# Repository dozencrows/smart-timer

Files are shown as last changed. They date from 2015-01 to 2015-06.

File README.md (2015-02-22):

smart-timer
===========
This is a test project for exploration of the NXP LPC810 ARM microcontroller.

It implements a dual countdown timer, capable of up to ten hour countdowns on each timer independently.

There is accompanying hardware that the code requires:
* MCP23008 I2C GPIO expander to interface 8 momentary switches to act as input
* 2N2222 transistor switching a piezo self-oscillating sounder
* MIC2545A smart switch controlling LCD power
* 16 x 2 character LCD display (hd44780 compatible)
* PCF8574 I2C GPIO expander to interface LCD display
* 3.3V power supply

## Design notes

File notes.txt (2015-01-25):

Smart Kitchen Timer - Design & Development Notes
================================================

Timer appearance: H:MM:SS

Two timer displays.

Buttons per timer:
    H:      +1 hour, stops timer
    M:      +1 minute, stops timer
    S:      +1 second, stops timer
    start:  toggle timer start/stop

Combined button actions:
    start and any of H, M, S buttons: stops & resets timer to 0:00:00.
    start1 + start2: toggle timer mode

Timer modes:
    Independent: each timer can be started & stopped independently.
    Chained: timer 1 runs first; on completion, triggers timer 2.
        Resetting either timer resets both.
        Actions that stop a timer stop both if running.
    
Alarm state:
    On reaching 0:00:00, a timer stops, emits an audible alarm and its display flashes.
    Pressing any button for that timer cancels the alarm, sets the timer back to starting value.

Structure:
    2 x timers
    1 x timer controller
    1 x alarm
    1 x input manager
    
Timer:
    States:
        STOPPED
        RUNNING
        PAUSED
        ALARM
    Events:
        Button events:
            H_b
            M_b
            S_b
            start_b
            start_b + H_b/M_b/S_b
        Control events:
            start
            stop
            update
            reset
            alarm
    Data:
        Current state
        Current H, M, S
        Starting H, M, S
    Behaviour:
        Global:
            reset:                  set H, M and S to zero, change to STOPPED state
            start_b + H_b/M_b/S_b:  send timer X reset event to controller
        
        STOPPED:
            H_b, M_b, S_b:          increment corresponding data and refresh display
            start_b:                send timer X start event to controller
            start:                  go to RUNNING state
            update:                 refresh display
            
        RUNNING:
            start_b, H_b, M_b, S_b: send timer X stop event to controller
            update:                 count down timer, refresh display - if zero, send timer X done to controller
            stop:                   go to PAUSED state
            alarm:                  go to ALARM state
            
        PAUSED:
            start_b, H_b, M_b, S_b: send timer X start event to controller
            update:                 refresh display
            start:                  go to RUNNING state
            
        ALARM:
            update:                 flash and refresh display
            start_b, H_b, M_b, S_b: set H, M, S to starting values, go to STOPPED state
        
Timer Controller:
    States:
        INDEPENDENT
        CHAINED
    Events:
        Button events:
            start_b1+start_b2
        Timer events:
            timer 1 start
            timer 2 start
            timer 1 stop
            timer 2 stop
            timer 1 reset
            timer 2 reset
            timer 1 done
            timer 2 done
    Data:
        current state
    Behaviour:
        Global:
            any:                    send clear to Alarm
        
        INDEPENDENT:
            timer X start:          send start to timer X
            timer X stop:           send stop to timer X
            timer X reset:          send reset to timer X
            timer X done:           send trigger to Alarm, send alarm to timer X
            
        CHAINED:
            timer X start:          if timer 1 running, send start to timer 1
                                    if timer 2 running, send start to timer 2
            timer X stop:           if timer 1 running, send stop to timer 1
                                    if timer 2 running, send stop to timer 2
            timer X reset:          send reset to timer 1 and timer 2
            timer X done:           if X == 1:
                                        send trigger to Alarm, send alarm to timer 1, send start to timer 2
                                    if X == 2:
                                        send trigger to Alarm, send alarm to timer 2        

Alarm:
    States:
        SILENT
        AUDIBLE
    Events:
        trigger
        clear
    Behaviour:
        Global:
        
        SILENT:
            trigger:    start audible alarm, go to AUDIBLE state
            
        AUDIBLE:
            clear:      stop audible alarm, go to SILENT state

Total events - 19:
    alarm trigger       Alarm control
    alarm clear
    timer 1 start       Timer controller notifications
    timer 2 start
    timer 1 stop
    timer 2 stop
    timer 1 reset
    timer 2 reset
    timer 1 done
    timer 2 done
    timer start         Timer behaviour control
    timer stop
    timer update        Model as update handler func
    timer reset
    timer alarm
    H_b                 Treat button combos as bitwise or of button events
    M_b
    S_b
    start_b
    
State Machine Design
    State:              
        enter func ptr
        event handler func ptr
        update handler func ptr
        exit func ptr
    States:
        array of structures
    Event handler:
        switch statement on event flag combos.
    Functions:
        get state
        set state

Input Manager
    Polls GPIO buttons/reads interrupt results
    Debounces and records combos
    Sends button events to appropriate timer
    
Count-down timers
    Use an MRT for each.
        Set value to full duration & start; read back value & convert to H:MM:SS for display, use callback to trigger done.
        Set a repeat MRT to expire after 1 second; use callback on that to update timer counts (simpler, less code?)

Available Piezo Sounders
========================
Bitsbox:
* ST013:    Murata PKM13EPYH40002 - 4kHz, external drive
* ST045:    Emech 2048kHz - electromagnetic! 'Ware polarity, may only be up to 3V. Wire diode in reverse in parallel instead of resistor.
* KPEG200A: Kingstate - continuous tone, just requires DC. 2600Hz - 3600Hz. 1.3mA draw.
* ST016:    ? - continuous tone, just requires DC. 2700Hz. 4.7mA draw.

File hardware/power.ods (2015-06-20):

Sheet: Sheet1
Battery capacity mAH | 1800 | Hours | Days
Idle draw mA | 0.319 | 5642.6332288401 | 235.1097178683
Input draw mA | 21 | 85.7142857143 | 3.5714285714
Timer draw mA | 5 | 360 | 15
Alarm draw mA | 9 | 200 | 8.3333333333

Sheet: Sheet2
Idle draw
3V3 side measured (mA) | 0.355
I2C level shift (mA) | 0.047
MCP23008 standby (mA) | 0
LPC810 deep sleep (mA) | 0.24 | R | 2.5 | V | 0.0006
3V3 from datasheet
LPC810 deep sleep (mA) | 0.3
MCP23008 standby (mA) | 0.001
MCP1700-3302 quiescent (mA) | 0.004
5V side measured (mA) | 0.458
I2C level shift (mA) | 0.448
LCD leakage (mA) | 0
MIC2454A (switch off) + LCD leakage (mA) | 0
5V from datasheet
MCP1700-5002 quiescent (mA) | 0.004
MIC2454A switch off (mA) | 0.005

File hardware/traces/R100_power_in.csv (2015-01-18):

trigger | stamp | channel | index | type | delay | factor | rate | count | data
20111 | 15:43:18 | 0 | 20110 | 0 | 5E-7 | 5 | 1.8E6 | 900 | 0.063375 | 0.056243 | 0.056604 | 0.052813 | 0.052813 | 0.052135 | 0.051052 | 0.050781 | 0.051142 | 0.050781 | 0.050014 | 0.050285 | 0.05024 | 0.050781 | 0.050781 | 0.050781 | 0.050781 | 0.050059 | 0.050375 | 0.050781 | 0.050601 | 0.05024 | 0.050962 | 0.050962 | 0.050781 | 0.051097 | 0.051549 | 0.051187 | 0.051594 | 0.049247 | 0.052135 | 0.051955 | 0.051278 | 0.051458 | 0.051368 | 0.051549 | 0.052 | 0.059312 | 0.065993 | 0.066083 | 0.063194 | 0.059132 | 0.055521 | 0.053174 | 0.05209 | 0.051187 | 0.051413 | 0.050059 | 0.05024 | 0.05033 | 0.05033
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

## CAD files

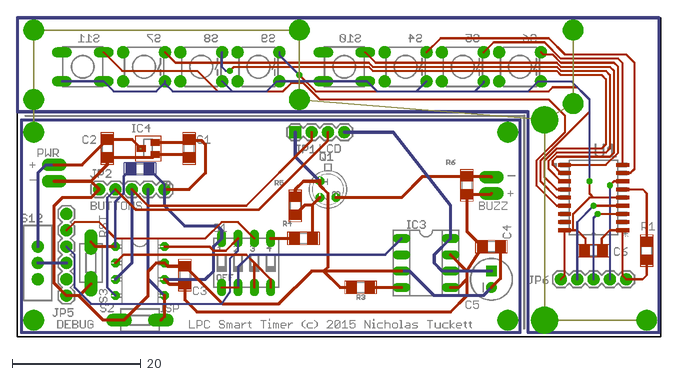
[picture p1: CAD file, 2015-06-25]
hardware/smart-timer-23009.dxf
100.2 x 49.7

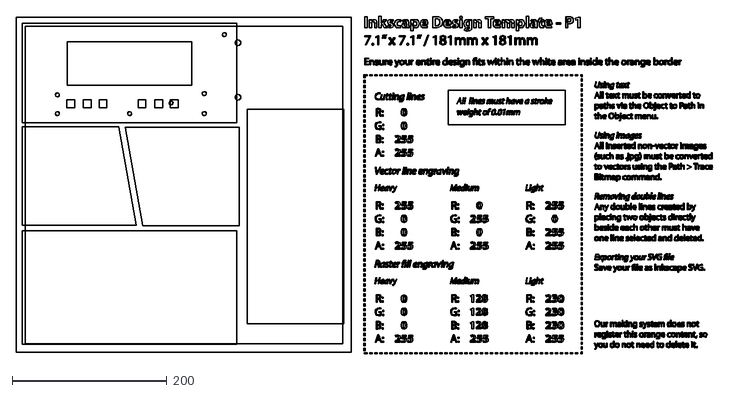
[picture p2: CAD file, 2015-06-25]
hardware/case.dxf
900.1 x 436.6

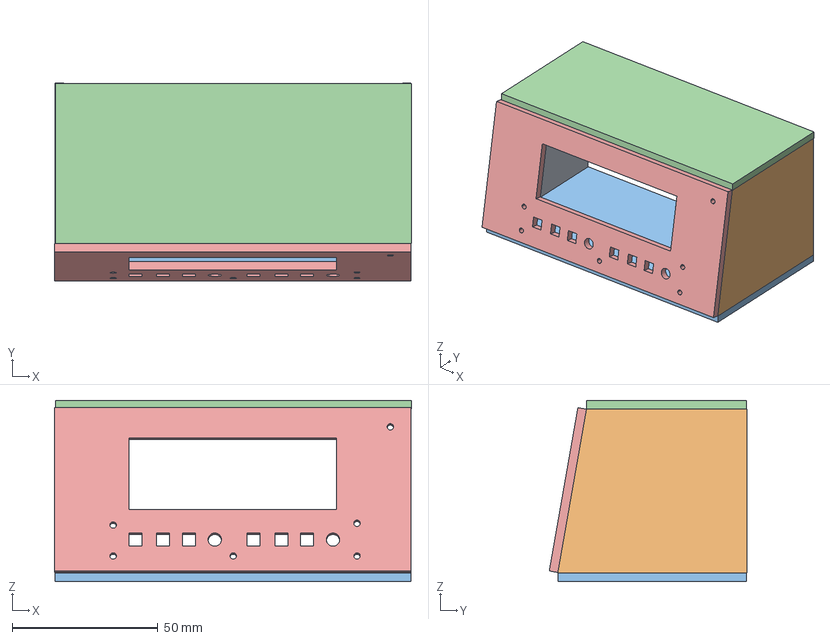
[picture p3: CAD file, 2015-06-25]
hardware/smart-timer-case.fcstd
122.6 x 67.8 x 62.2 mm
Cut014 (Solid)

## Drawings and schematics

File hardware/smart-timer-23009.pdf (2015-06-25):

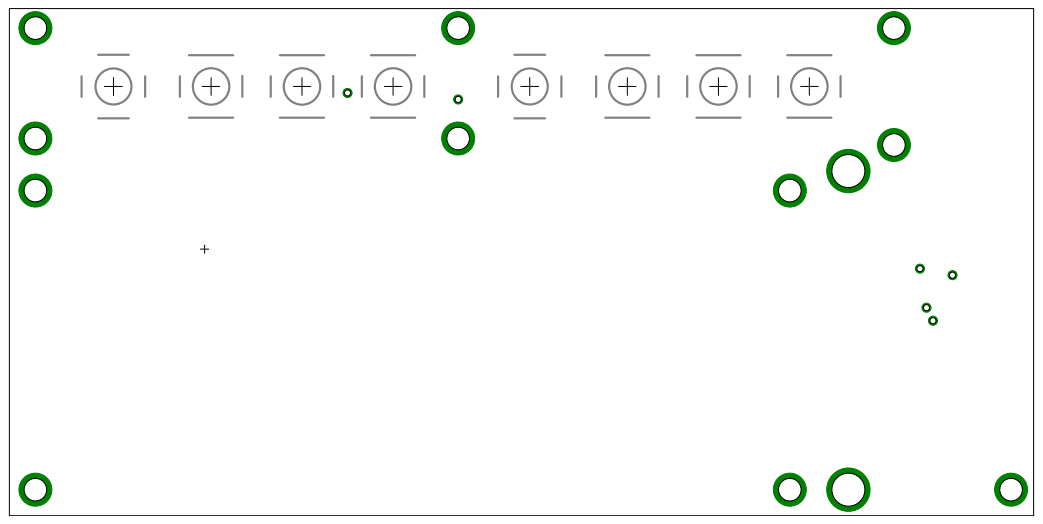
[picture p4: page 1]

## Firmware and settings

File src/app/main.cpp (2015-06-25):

//=======================================================================
// Copyright Nicholas Tuckett 2015.
// Distributed under the MIT License.
// (See accompanying file license.txt or copy at
//  http://opensource.org/licenses/MIT)
//=======================================================================

// Port & pin usage:
//	Pin	Port	Dir	    Usage			        Pull	Default
//	-----------------------------------------------------------------
//	1	PIO0_5	In	    Reset			        Up	    Reset (in)
//	2	PIO0_4	Out	    Buzzer on/off, UART TXD	Up	    PIO0_4 (in), UART TXD in ISP
//	3	SCL	    Out	    I2C			            Up	    SWDIO
//	4	SDA	    In/Out	I2C			            Up	    SWCLK
//	5	PIO0_1	In	    Button interrupt	    Up	    PIO0_1 (in), ISP if low on reset
//	6	VDD		        Power
//	7	VSS		        Ground
//	8	PIO0_0	Out	    LCD power		        Up	    PIO0_0 (in), UART RXD in ISP
//

// Programming mode means:
//  Switch LCD power connection to UART RXD (and force actual power switch to high)
//  Switch Buzzer connection to UART TXD

// Debugging mode means
//  Switch Buzzer connection to UART TXD

#include "string.h"
#include "serial.h"

#include "lpc_types.h"
#include "romapi_8xx.h"

#include "util/timers.h"
#include "util/lcd.h"
#include "util/mrt_interrupt.h"

#include "timer_controller.h"
#include "buzzer.h"
#include "backlight.h"
#include "button_input.h"


// Set this define to add debugging aids in code, and configure UART
// output to replace buzzer control
//#define DEBUG

#define LOOP_STEP_MS        64
#define BUZZER_GPIO         4
#define INPUT_I2C_ADDR      0x20

uint32_t SystemMainClock = FIXED_CLOCK_RATE_HZ;
uint32_t SystemCoreClock = FIXED_CLOCK_RATE_HZ;

const char hexdigit[] = "0123456789abcdef";

uint32_t i2cBuffer [24];
I2C_HANDLE_T* ih;

void error(const char* msg) {
    puts("\n**ERROR: ");
    puts(msg);
    putchar('\n');
}

void errorWithCode(const char* msg, int code) {
    puts("\n**ERROR: ");
    puts(msg);
    putchar(' ');
    
    for (int i = 24; i >= 0; i-=4) {
        putchar(hexdigit[(code >> i) & 0xf]);
    }
    putchar('\n');
}

static void i2cSetup () {
    LPC_SWM->PINENABLE0 |= 3<<2;            // disable SWCLK and SWDIO

    // Keep internal pull-ups on I2C pins, as this works and is less
    // power draining when LCD off and in low power state
    
    LPC_SWM->PINASSIGN7 = 0x02FFFFFF;       // SDA on P2, pin 4
    LPC_SWM->PINASSIGN8 = 0xFFFFFF03;       // SCL on P3, pin 3
    LPC_SYSCON->SYSAHBCLKCTRL |= (1<<5);    // enable I2C clock

    ih = LPC_I2CD_API->i2c_setup(LPC_I2C_BASE, i2cBuffer);
    if (ih == NULL)
        error("i2c_setup");
        
    if (LPC_I2CD_API->i2c_set_bitrate(ih, 12000000, 100000) != LPC_OK)
        error("i2c_set_bitrate");

    if (LPC_I2CD_API->i2c_set_timeout(ih, 100000) != LPC_OK)
        error("i2c_set_timeout");
}

static void configureLowPowerPins() {
    // Set PIO0_10 and 11 as low outputs, as they float.
    // This saves some power
    LPC_GPIO_PORT->DIR0 |= 3 << 10;
    LPC_GPIO_PORT->CLR0  = 3 << 10;
}

static void deepSleep() {
    LPC_SYSCON->STARTERP0   = 0x01; // pin interrupt 0 will wakeup 
    LPC_PMU->PCON           = 0x01; // select deep sleep
    SCB->SCR                = SCB_SCR_SLEEPDEEP_Msk;
    __WFI();
    LPC_PMU->PCON           = 0;
    SCB->SCR                = 0;
}

static void powerDown() {
    LPC_SYSCON->STARTERP0   = 0x01; // pin interrupt 0 will wakeup 
    LPC_PMU->PCON           = 0x02; // select power down
    SCB->SCR                = SCB_SCR_SLEEPDEEP_Msk;
    __WFI();
    LPC_PMU->PCON           = 0;
    SCB->SCR                = 0;
}

static void lcdPowerOn() {
    LPC_GPIO_PORT->B0[0] = 1;
}

static void lcdPowerOff() {
    LPC_GPIO_PORT->B0[0] = 0;
}

static void initLcdPowerSwitch() {
    LPC_SWM->PINASSIGN0 |= 0xff00;          // ensure pin 8 is not assigned to UART RXD  
    LPC_GPIO_PORT->DIR0 |= 1;               // set GPIO 0 output (to control LCD power)
    lcdPowerOn();
}

int main () {
#if defined(DEBUG)
    // Ensure UART TXD is on 
    LPC_SWM->PINASSIGN0 &= 0xffffff00;
    LPC_SWM->PINASSIGN0 |= 0x00000004;
#else
    LPC_SWM->PINASSIGN0 |= 0xff;
#endif

    configureLowPowerPins(); 
    timersInit();
    serial.init(LPC_USART0, FIXED_UART_BAUD_RATE);
    delayMs(100);
    puts("Smart Timer");
    i2cSetup();
    
    initLcdPowerSwitch();
        
    Buzzer::Initialise();
    Timer::Initialise();
    Backlight::Initialise();
    ButtonInput::Initialise();

    lcdInit();
    
    Backlight       backlight;
    Buzzer          buzzer(BUZZER_GPIO);
    TimerController timer_controller(buzzer, backlight);
    ButtonInput     button_input(INPUT_I2C_ADDR);
    
    mrt_interrupt_control(true);
    backlight.DelayedOff(BACKLIGHT_ON_TIME_MS);
    
    while (true) {
        while (button_input.HasButtonStateChanged()) {
            timer_controller.ProcessButtons(button_input.GetButtonStates());
        }

        timer_controller.Update();
        
        if (!button_input.HasButtonStateChanged()) {
            if (timer_controller.IsIdle() && !backlight.IsOn()) {
                lcdPowerOff();
                powerDown();

                lcdPowerOn();
                delayMs(10);
                
                backlight.On();
                buzzer.Beep();
                
                if (button_input.HasButtonStateChanged()) {
                    button_input.DiscardNextState();
                }
                
                lcdInit();
                timer_controller.ForceUpdate();
            }
            else {
                __WFI();
            }
        }
    }
}

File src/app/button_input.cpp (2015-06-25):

//=======================================================================
// Copyright Nicholas Tuckett 2015.
// Distributed under the MIT License.
// (See accompanying file license.txt or copy at
//  http://opensource.org/licenses/MIT)
//=======================================================================

/*
 * GPIO extender button input implementation
 *
 * Sets up MCP23008 expander for all pins to be inputs with pull-ups.
 * Assumes MCP23008 interrupt pin is connected to PIO0_1 (pin 5 on LPC810)
 * PIO0_1 is left in default post-reset state:
 *  - its PINENABLE0 bit is 1 so no special function is active - no change needed
 *  - GPIO means no movable function should be assigned to this pin - no change needed
 *  - Input GPIO means 0 in bit for direction register - no change needed
 */
 
#include "button_input.h"

#include "LPC8xx.h"
#include "util/mcp.h"
#include "util/timers.h"

#define POST_READ_DELAY_MS  8

static volatile int buttonIRQCount = 0;

extern "C" void PININT0_IRQHandler(void) {
    if (LPC_PIN_INT->FALL & 1) {
        LPC_PIN_INT->FALL = 1;
        buttonIRQCount++;
    }
}

void ButtonInput::Initialise() {
    // Configure pin interrupt for PIO0_1
    LPC_SYSCON->PINTSEL[0]      = 1;        // Pin interrupt 0 from PIO0_1
    LPC_PIN_INT->ISEL           = 0;        // Level sensitive (1 bit per pin interrupt)
    LPC_PIN_INT->IENF           = 1;        // Falling level   (1 bit per pin interrupt)
    LPC_SYSCON->SYSAHBCLKCTRL  |= 1<<6;     // Turn on clock to pin interrupts block (already 1 after reset)
    NVIC_EnableIRQ(PININT0_IRQn);           // Enable pin interrupt in NVIC (#24)
}

ButtonInput::ButtonInput(uint8_t i2c_addr) : i2c_addr_(i2c_addr), button_state_(0) {
    mcpWriteRegister(i2c_addr_, MCP23008_IODIR, 0xff);   // 0-7: input
    mcpWriteRegister(i2c_addr_, MCP23008_GPPU, 0xff);    // 0-7: pull-up
    mcpWriteRegister(i2c_addr_, MCP23008_IPOL, 0xff);    // 0-7: invert
    mcpWriteRegister(i2c_addr_, MCP23008_GPINTEN, 0xff); // 0-7: interrupt on change. Interrupt pin is active low
}

uint8_t ButtonInput::GetButtonStates() {
    if (buttonIRQCount > 0) {
        __disable_irq();
        buttonIRQCount--;
        __enable_irq();
        button_state_ = mcpReadRegister(i2c_addr_, MCP23008_GPIO);
    }
    
    return button_state_;
}

void ButtonInput::DiscardNextState()
{
    GetButtonStates();
}

bool ButtonInput::HasButtonStateChanged() {
    return buttonIRQCount > 0;
}

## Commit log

2015-01-04 Initial implementation and test of fundamental countdown timer
2015-01-04 Added flashing alarm state to timers
2015-01-04 Implemented timer controller for independent timers
2015-01-04 Refactored buzzer into its own controller class, and added beep capability
    [buzzer.cpp, main.cpp]
2015-01-18 Added hardware folder, with test oscilloscope trace
    [R100_power_in.csv]
2015-01-18 Switched to MCP23008 as GPIO extender
2015-01-18 Only read from MCP GPIO extender on its interrupt signal
2015-01-19 WIP on interrupt driven main loop
2015-01-20 Refine button IRQ handling to improve responsiveness
2015-01-20 Buzzer now only turns on SysTick interrupt when active
    [buzzer.cpp]
2015-01-24 Refactored button reading via GPIO into separate module; removed printf to save memory
2015-01-24 Finished refactoring button input handling
2015-01-25 Added continuous tone buzzer support; notes & plan update for piezo sounder tests
    [buzzer.cpp]
2015-01-28 Implemented deep-sleep mode for saving some power
2015-01-28 WIP: switching LCD power from GPIO
2015-01-31 WIP: turn off LCD as power save
2015-01-31 Move LCD GPIO power setup to earlier in startup
2015-02-06 Added power calculation sheet
    [power.ods]
2015-02-06 Updated sleep mode for active-high smart switch instead of MOSFET
2015-02-07 Experiment with I2C disabling to see if power saved - but doesn't
    [main.cpp]
2015-02-07 Removed i2c disable code. Fixed early return to sleep on short button press
    [main.cpp]
2015-02-15 Updated power calcs with switch to 3.3v LCD
    [power.ods]
2015-04-12 Switch to power down mode for greater power save
    [power.ods]
2015-05-13 Switched buzzer pin to allow RESET, added debug mode with UART switched in
    [main.cpp]
2015-05-14 Added note on I2C pull ups in low power state, and removed temps
2015-06-20 Revised button mapping to match PCB
    [power.ods]
2015-06-25 Added case design files
    [case.dxf, smart-timer-23009.dxf, smart-timer-case.fcstd]
2015-06-25 Button press when in sleep now only wakes, not affect timer state
2015-06-25 Tweak LCD init and backlight timer behaviour
